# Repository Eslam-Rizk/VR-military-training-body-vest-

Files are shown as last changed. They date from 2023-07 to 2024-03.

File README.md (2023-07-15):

# Project overview
This project can be used to provide realistic experience while playing video games or even provide realistic training to military personnel.The idea is to connect the vest to a video game through usb port using **Esp8266 NodeMCU** board and receive hits and injuries data from the game and make it felt using sounds, lights and vibration motors.

# Components
* 2 x Esp8266 NodeMcu (transmitter & receiver).
* 1 x Arduino Mega2560.
* 2 x 3.7v Li-ion battery in series.
* 1 x LM7805.
* 1 x 0.01 uf ceramic capacitor.
* 1 x 0.1 uf radial capacitor.
* 1 x toggle switch.
* 7 x mini vibration motors.
* 1 x buzzer.
* 7 x yellow & red LEDs.
* 2 x green LEDs.
* 7 x 2n2222 transisors.
* 8 x 1k ohm, 14 x 100 ohm and 7 x 27 ohm resistors.
* PCBs and Ethernet wires

# Code
* Check out the transmitter NodeMcu code [here](https://github.com/Eslam-Rizk/VR-military-training-body-vest-/blob/main/VR%20military%20training%20vest/master_transmitter/master_transmitter.ino).
* Check out the receiver NodeMcu code [here](https://github.com/Eslam-Rizk/VR-military-training-body-vest-/blob/main/VR%20military%20training%20vest/shooter1_receiver/shooter1_receiver.ino)
* Check out the Arduino Mega2560 code [here](https://github.com/Eslam-Rizk/VR-military-training-body-vest-/blob/main/VR%20military%20training%20vest/shooter1_code/shooter1_code.ino)

# Steps
* At first we program the 2 NodeMcu and the arduino mega2560 using Arduino IDE and the codes above.
* Design the body PCBs on **Proteus Ares** using the circuit diagram below:
  
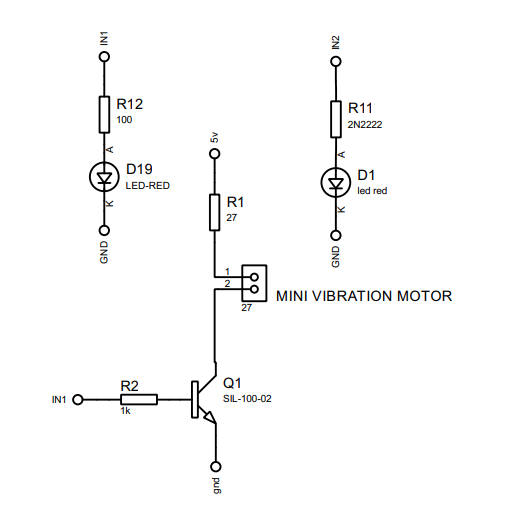
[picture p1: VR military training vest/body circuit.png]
ody circuit
  

  here is the body PCB:
  
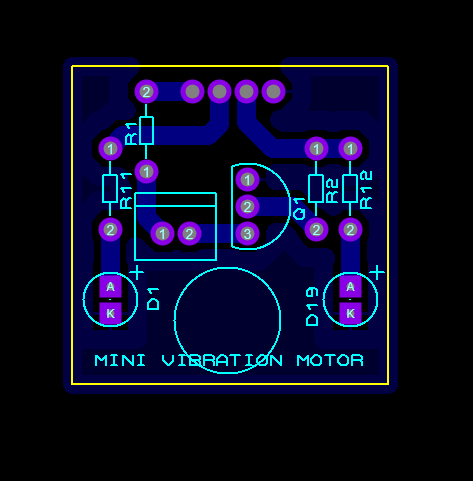
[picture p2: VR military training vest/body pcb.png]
body pcb
  
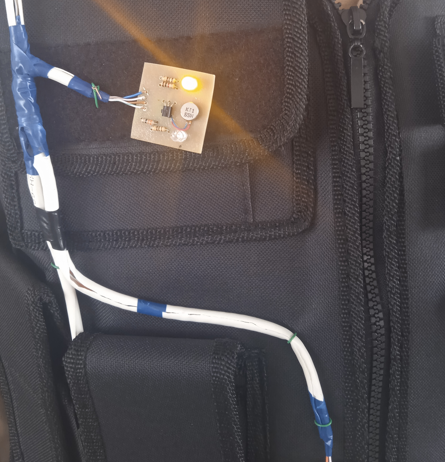
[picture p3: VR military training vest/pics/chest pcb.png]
  
  
* Design the head PCB using the circuit diagram below:
  
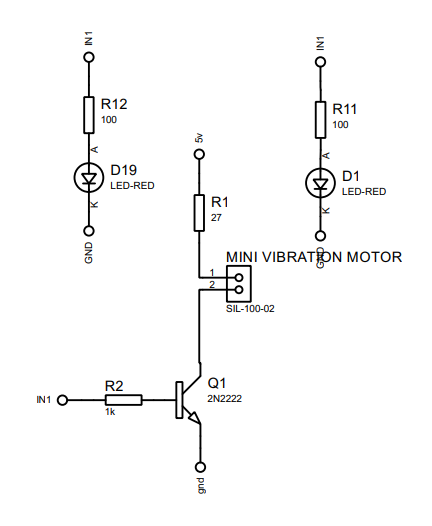
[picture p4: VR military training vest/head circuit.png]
head
  

  here is the head PCB:
  
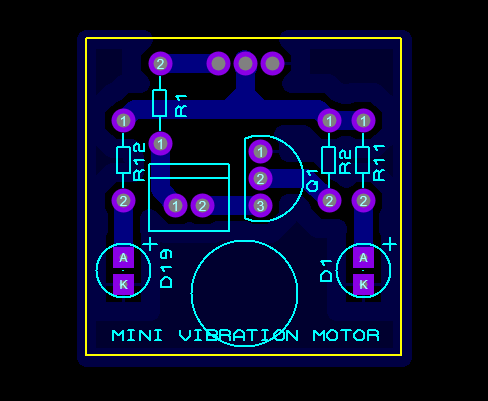
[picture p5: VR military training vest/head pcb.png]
head pcb
  
  
* Design the alarm PCB using the circuit diagram below:
  
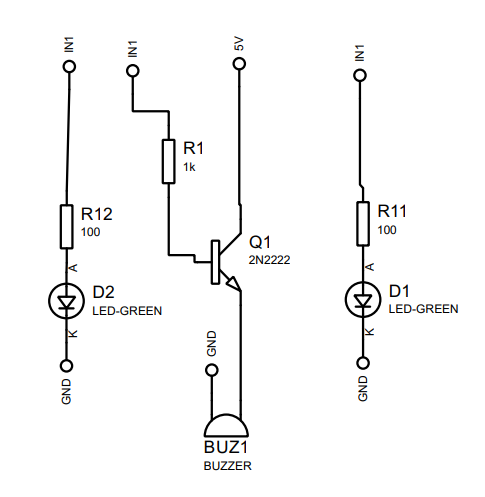
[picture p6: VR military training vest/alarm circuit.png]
alarm
  

  and here is the alarm pcb:
  
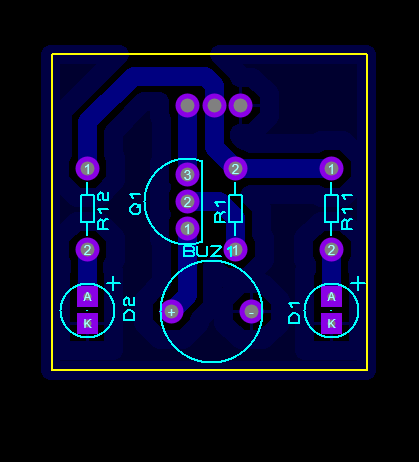
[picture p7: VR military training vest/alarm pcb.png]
alarm pcb
  
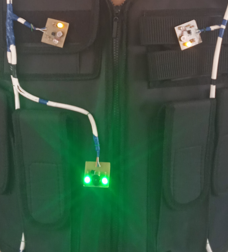
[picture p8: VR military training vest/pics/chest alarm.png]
alarm pcb
  
  
* Connect one Esp8266 NodeMcu (transmitter) to computer using usb cable.
* Then we wire up the other Esp8266 NodeMcu (receiver) to the Arduino board as shown below:
  
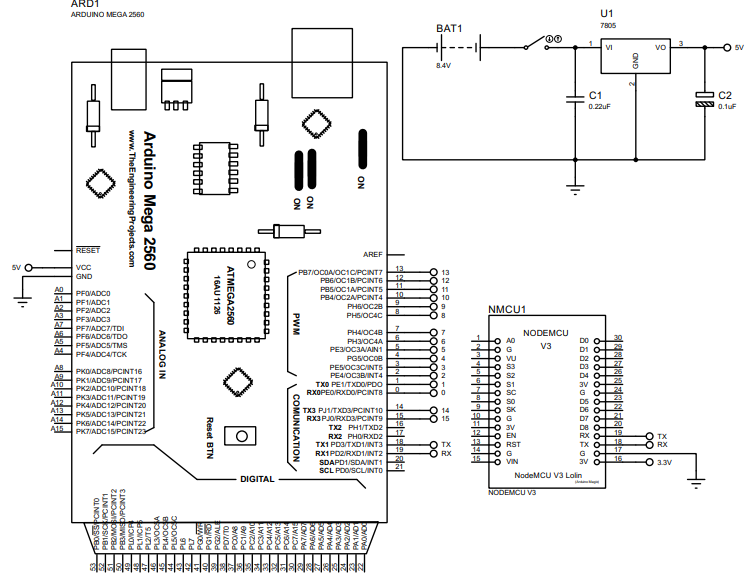
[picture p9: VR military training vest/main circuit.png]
main circuit
  

# Notes
* There are 7 PCBs, one for each arm and Legs, two for chest, one for head and one for alarm.
* Each PCB is connected to te arduino through 2 pins, one fo each LED Exept for head and alarm they are connected through 1 pin only.
* For the PCBs connected through 2 pins, the yellow LED means 1 shot and the red LED means 2 shot and alarm is activated meaning **GAMEOVER**.
* From pin 2 to pin 13, pin 2 and pin 3 is connected to the right arm PCB, pin 4 and 5 is connected to the left arm PCB and so on.
* Pin 14 is connected to the head PCB and pin 15 is the alarm pin.

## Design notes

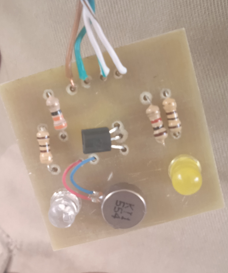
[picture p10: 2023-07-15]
VR military training vest/pics/leg pcb.png

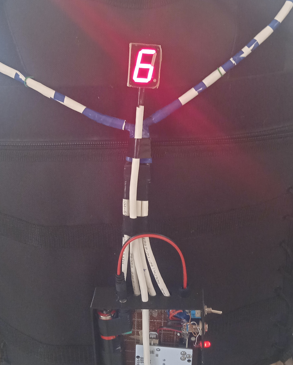
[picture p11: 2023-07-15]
VR military training vest/pics/hits.png

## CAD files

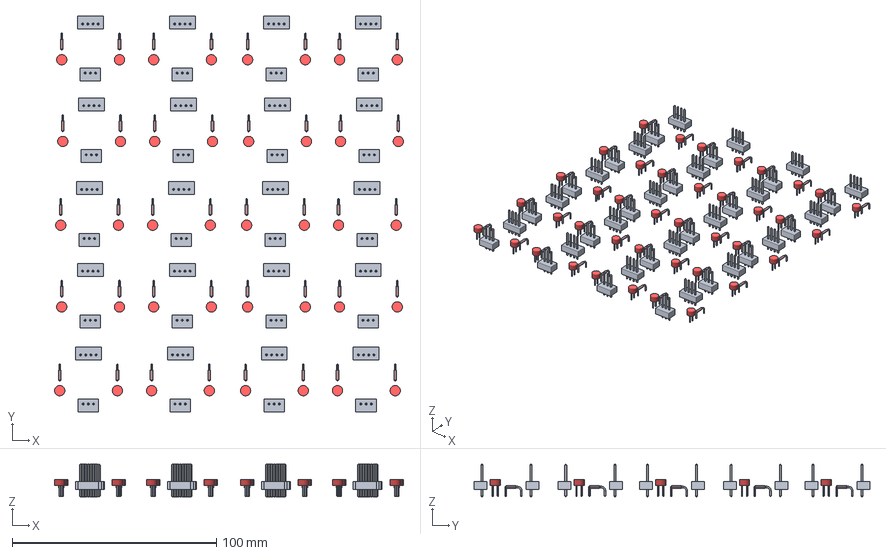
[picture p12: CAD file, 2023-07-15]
VR military training vest/proteus circuit/vest pcb.STEP
170.9 x 193.7 x 16.0 mm
Pin_1 x 120
Pin_2 x 120
Pin_3 x 40
Pin_4 x 20

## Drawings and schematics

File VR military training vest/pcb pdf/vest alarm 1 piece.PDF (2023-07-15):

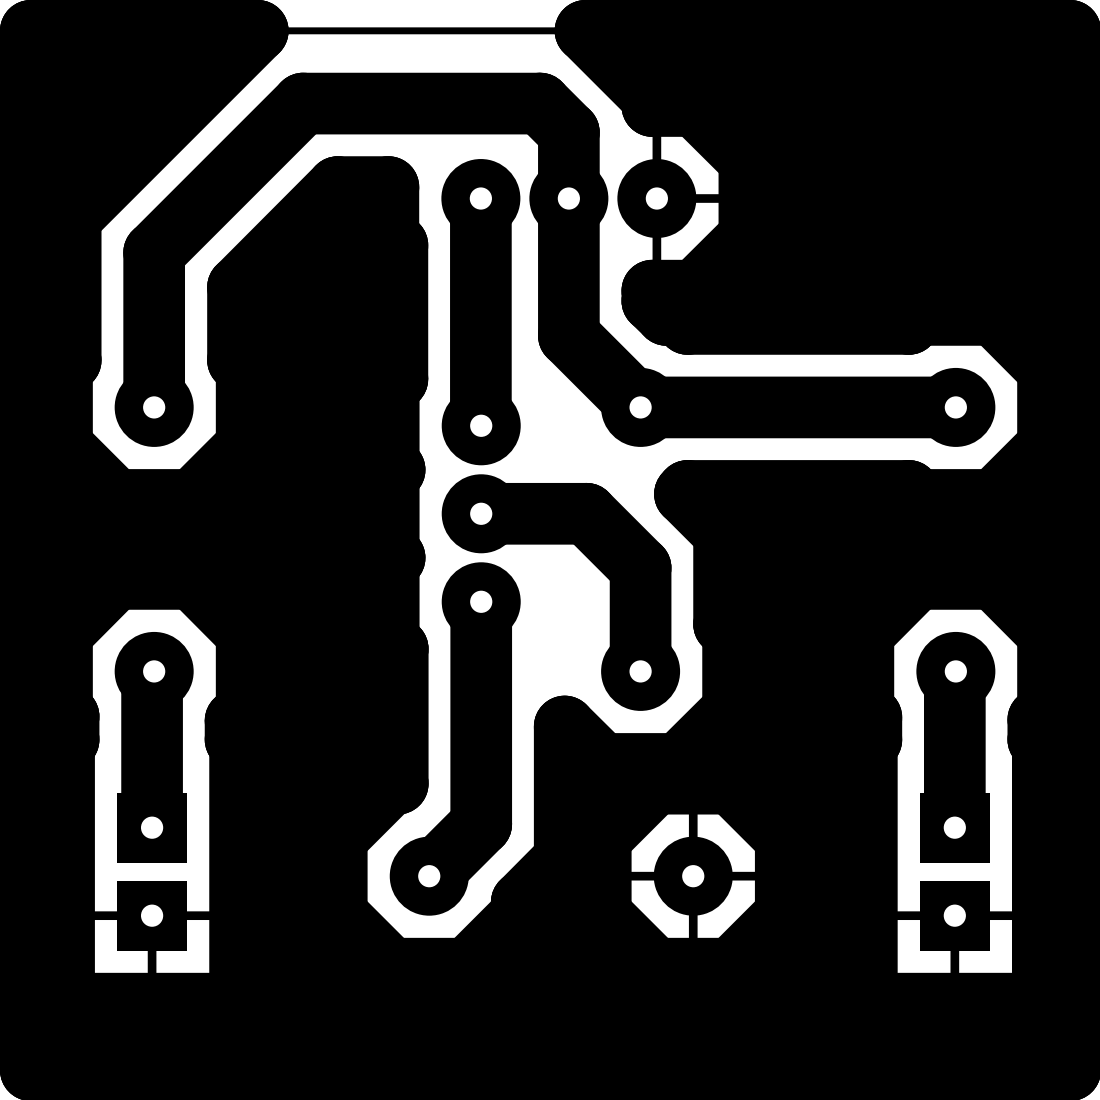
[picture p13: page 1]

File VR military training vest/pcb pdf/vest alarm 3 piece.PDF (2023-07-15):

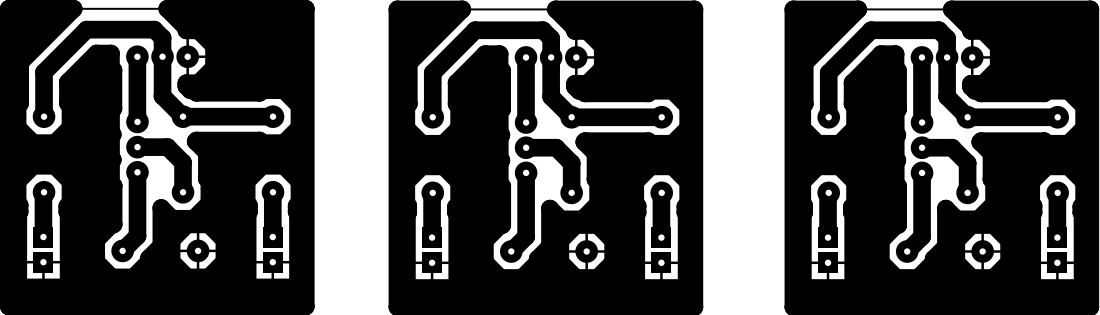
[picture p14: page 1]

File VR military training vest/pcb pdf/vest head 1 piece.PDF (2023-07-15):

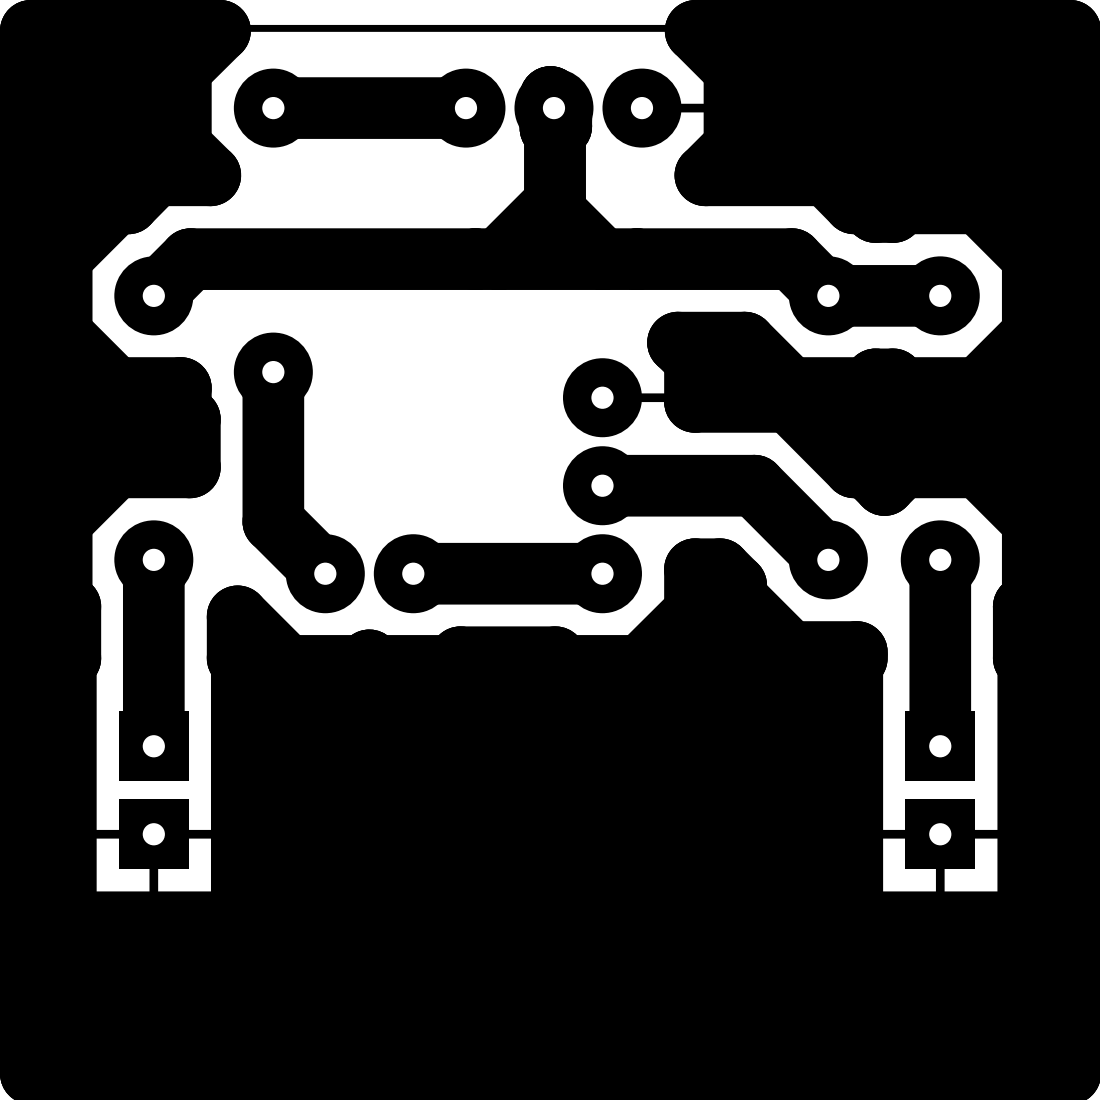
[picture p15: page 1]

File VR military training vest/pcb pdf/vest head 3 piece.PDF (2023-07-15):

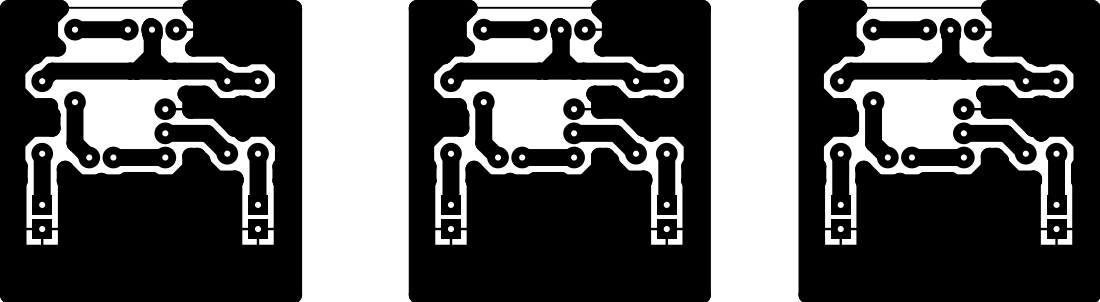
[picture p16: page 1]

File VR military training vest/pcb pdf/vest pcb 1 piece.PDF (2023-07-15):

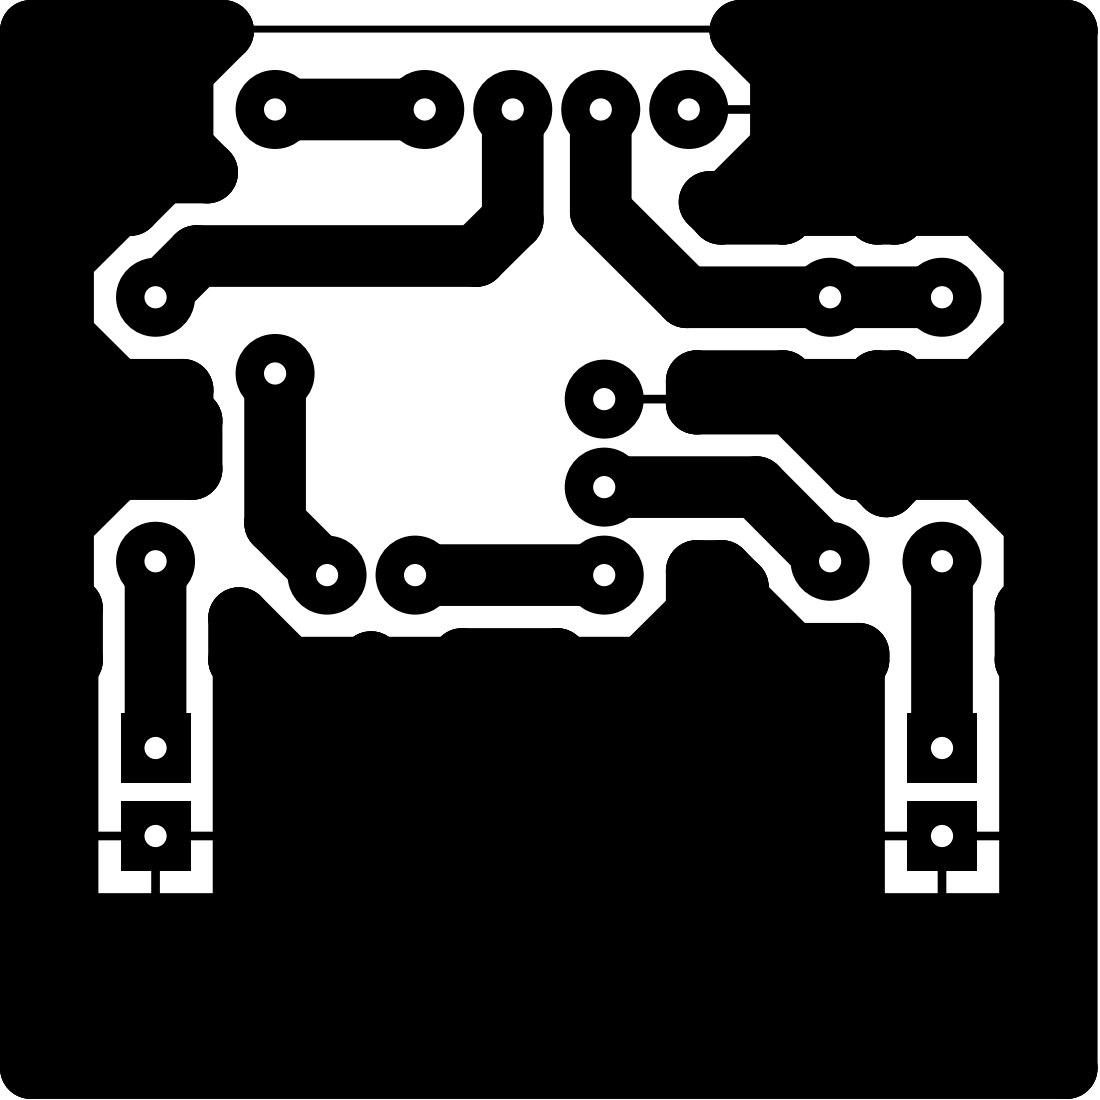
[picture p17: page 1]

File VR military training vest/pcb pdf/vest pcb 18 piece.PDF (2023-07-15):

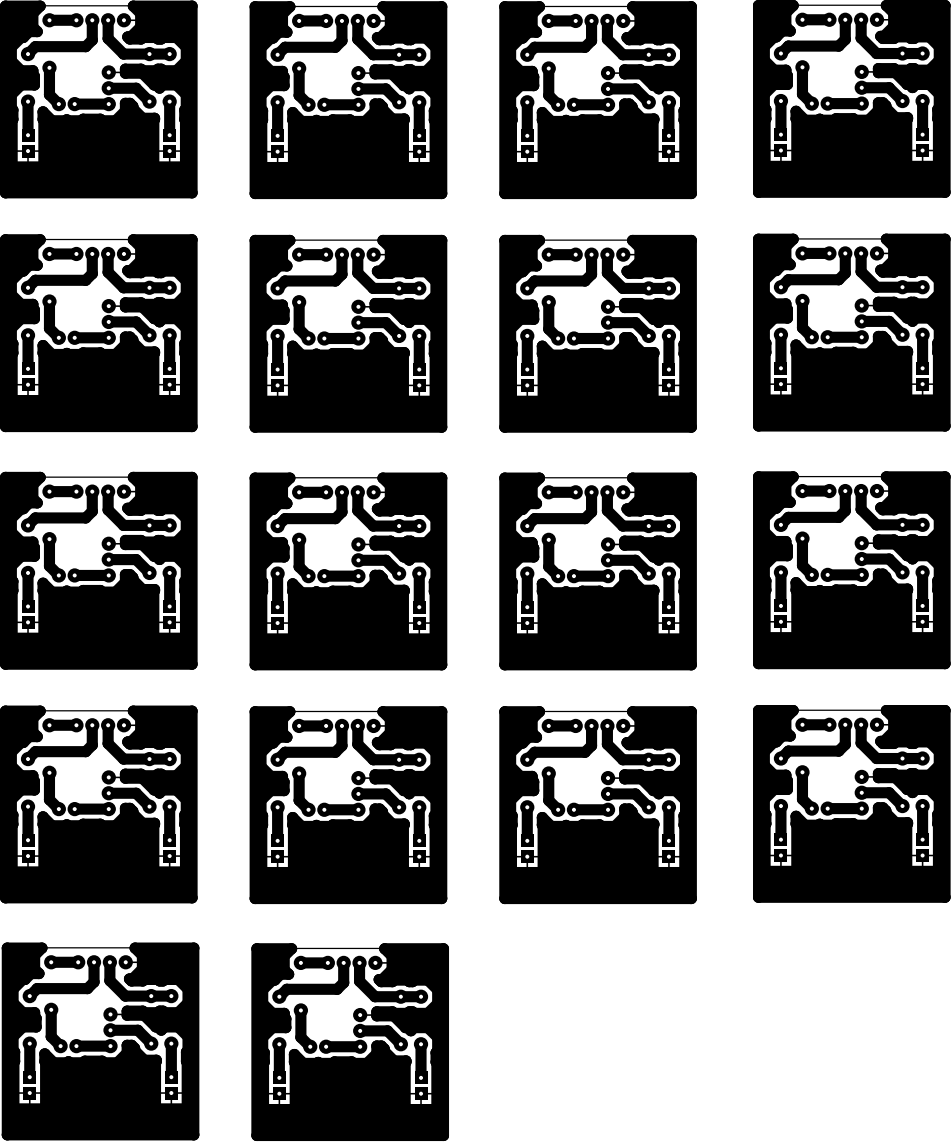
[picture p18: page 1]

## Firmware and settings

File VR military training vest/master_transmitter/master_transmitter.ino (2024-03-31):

#include <ESP8266WiFi.h>
#include <WiFiUdp.h>
#include <EEPROM.h>

const char* ssid = "Shooting simulator";
const char* password = "11111111";

WiFiUDP Udp;
unsigned int localUdpPort = 4210;  // local port to listen on
char incomingPacket[255];  // buffer for incoming packets
char  replyPacket[] = "Hi there! Got the message :-)";       // a string to send back
char  Data[] = "";
int randomIndex;

IPAddress masterIP(192,168,1,10);         //master ip
IPAddress gateway(192,168,1,1);
IPAddress subnet(255,255,255,0);
IPAddress SH1(192,168,1,11);              //shooter1 ip
IPAddress SH2(192,168,1,12);              //shooter2 ip
IPAddress SH3(192,168,1,13);               //shooter3 ip


void setup() {

  WiFi.softAPConfig(masterIP, gateway, subnet);      //configure access point mode
  WiFi.softAP(ssid, password);
  WiFi.mode(WIFI_AP);
  
  Serial.begin(9600);                               //start serial port at 9600 baud rate
  Serial.println();
  Serial.print("Configuring access point...");

  delay(500);
  if(EEPROM.read(1)>9) {EEPROM.write(1, 1);delay(100);}           //eeprom to change sequence of random() data because it has fixed sequences
  EEPROM.write(1, EEPROM.read(1)+1);
  if(EEPROM.read(1)>9) {EEPROM.write(1, 1);delay(100);}

  IPAddress myIP = WiFi.softAPIP();
  Serial.print("AP IP address: ");
  Serial.println(myIP);
  Udp.begin(localUdpPort);
  Serial.printf("Now listening at IP %s, UDP port %d\n", WiFi.localIP().toString().c_str(), localUdpPort);
}

void loop() {
  // if there's data available, read a packet
  int packetSize = Udp.parsePacket();
  if (packetSize)
  {
    // receive incoming UDP packets
    //Serial.printf("Received %d bytes from %s, port %d\n", packetSize, Udp.remoteIP().toString().c_str(), Udp.remotePort());
    int len = Udp.read(incomingPacket, 255);
    if (len > 0)
    {
      incomingPacket[len] = 0;
    }
    Serial.println(incomingPacket);

    if(String(incomingPacket)=="GameOver1"){                 //check received data from unity game
      Serial.write("GameOver1");
      }
    else if(String(incomingPacket)=="GameOver2"){
      Serial.write("GameOver2");
      }
    else if(String(incomingPacket)=="GameOver3"){
      Serial.write("GameOver3");
      }
  }
  if(Serial.available()){
    char z=Serial.read();
    if(z=='x'){
     String shooters[3]={"sh1","sh2","sh3"};
     int h=EEPROM.read(1);
      for(int i=0;i<=10-h;i++){
         randomIndex=(int)random(0,3);                   //get random body part number
        }
     //int randomIndex=(int)random(0,3);
     String unityData=shooters[randomIndex];
     Serial.print(unityData);
     
    if(unityData=="sh1"){//shooter1
      Udp.beginPacket(SH1,4210);
      }//shooter1
    else if(unityData=="sh2"){//shooter2
      Udp.beginPacket(SH2,4210);
      }//shooter2
    else if(unityData=="sh3"){//shooter3
      Udp.beginPacket(SH3,4210);
      }//shooter3
      Udp.write('x');
      Udp.endPacket();
      
    }
    else if(z=='r'){
      Udp.beginPacket(SH1,4210);
      Udp.write('r');
      Udp.endPacket();
      delay(100);
      Udp.beginPacket(SH2,4210);
      Udp.write('r');
      Udp.endPacket();
      delay(100);
      Udp.beginPacket(SH2,4210);
      Udp.write('r');
      Udp.endPacket();
      delay(100);
      }
    }
    delay(1);

}

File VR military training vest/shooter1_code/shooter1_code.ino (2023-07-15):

#include <EEPROM.h>

int body[14]={0,0,0,0,0,0,0};//index: 0=head,1=left leg,2=right leg,3=left chest,4=right chest,5=left hand,6=right hand
int randomNumber;
String z="";

void setup(){
  
  delay(100);
  Serial.begin(9600); //start serial port at 115200 baud rate
  Serial.println();
//  EEPROM.begin(512);
  if(EEPROM.read(1)>9) {EEPROM.write(1, 1);delay(100);}           //eeprom to change sequence of random() data because it has fixed sequences
  EEPROM.write(1, EEPROM.read(1)+1);
  if(EEPROM.read(1)>9) {EEPROM.write(1, 1);delay(100);}
  
  pinMode(16,INPUT); 
  
  for(int i=2;i<16;i++){  //set body pins to l
    pinMode(i,OUTPUT);
    digitalWrite(i,LOW);
    delay(10);
    }
  
  
}

void loop(){
 
  if(Serial.available()){ //if data is ready to read
    char d=Serial.read();
    
    if(d=='x'){                                             //if got shot
      int h=EEPROM.read(1);
      //Serial.println(h);
      for(int i=0;i<=10-h;i++){
         randomNumber=(int)random(0,7);                   //get random body part number
        }                            

      //Serial.println(randomNumber);
      if(randomNumber==0){                                        //if randomNumber is head number, activate led and vibration
        digitalWrite(14,HIGH);
        goto gameOver;}                                               //goto gameOver part
      
      if(body[randomNumber]==0 && randomNumber!=0){                                   //if body[randomNumber] has no damage
        body[randomNumber]=1;                                     //set the damage of body[randomNumber] to 1
        digitalWrite(int(randomNumber*2+1),HIGH);                   //set the 1st damage of body Part((randomNumber*2+1)) led to high
        delay(10);
        
        }
        
        else{                                                      //if there is damage already
          gameOver:                                                    
          Serial.write("GameOver1");                                //shooter is dead ,send gameOver to esp reciever then to esp transmitter then to game to stop shooter weapon from firing
          digitalWrite(int(randomNumber*2),HIGH);             //set the 2nd damage of body Part((randomNumber*2)) led to high
          delay(10);
          while(digitalRead(16)==HIGH){                       //activate the buzzer until reset pin is clicked or 'r' --> (reset) is revcieved
            if(Serial.available()){                            //if 'r' -->(reset) is recieved ,stop buzzer and reset pins to low
              if(Serial.read()=='r'){
                if(digitalRead(14)==HIGH) digitalWrite(14,LOW);
                for(int i=0;i<14;i++){                        //reset body damage by seting body array to 0
                  body[i]=0;
                  }
                  delay(100);
                 for(int i=2;i<16;i++){                        //set body pins to low
                    if(digitalRead(i)==HIGH) digitalWrite(i,LOW); 
                    }
              delay(100);
              goto here;                                                      //break from (while) loop 
              }}
            digitalWrite(15,HIGH);
            delay(250);
            digitalWrite(15,LOW);
            delay(250);
           }
            here:
            if(digitalRead(14)==HIGH) digitalWrite(14,LOW);                                    //set head pin to low
            for(int i=0;i<14;i++){                                     //by pressing push Button, reset body damage by setting body array to 0
              body[i]=0;
              }
            for(int i=2;i<16;i++){                                   //set body pins to low
                digitalWrite(i,LOW);
                }
            }
            delay(100);
      
         }
      
        else if(d=='r'){                                           //reset while shooter still alive when'r' --> (reset) is revcieved
          digitalWrite(14,LOW);
          for(int i=0;i<14;i++){                                      //reset body damage by seting body array to 0
             body[i]=0;
             }
         delay(100);
         for(int i=2;i<16;i++){                                      //set body pins to low
            digitalWrite(i,LOW);
              }
         delay(100);
        }
    }
}
  
